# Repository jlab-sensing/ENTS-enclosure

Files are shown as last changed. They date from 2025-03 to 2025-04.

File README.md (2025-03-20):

# ENTS Node Enclosure

If you are looking to get started right away here is the instruction manual! [Instruction Manual](https://docs.google.com/document/d/11tFU89lwRSyXelN36C8FMLKuBJrCtldJ0RzkJU0yMCk/edit?usp=sharing)

### Project Summary

Before beginning the MAE 156 project, researchers using the ENTS generally used an IP68 rated Polycase enclosure to house the node during outdoor deployments. This was an undesirable solution because it was not cost effective at about $49 USD to house a single node and because it required researchers to modify the enclosure to suit their needs regarding cable connections. This was what led the project’s sponsor, Steve Taylor, to form the ENTS team in order to produce a new enclosure with the goal of it also being open-source. There is a need for an enclosure for the ENTS node that follows the following functional requirements: 
   - Low cost (< $40)
   - Accessible to environmental researchers across the country
   - Waterproof
   - Is non-toxic to the environment in which it is deployed in 
   - Does not interfere with data transmission
   - Can allow for variable number of cable connections
   
The goal of the enclosure for the ENTS node is to improve the node's performance for researchers during deployments. Having an enclosure made specifically for their purposes would mean that they would not have to spend resources on tailoring it to their preferences and environments. Having a secure enclosure also prevents leakage, ensuring that the node does not get damaged during deployment. To address these requirements, this project developed two designs: a 3D-printed enclosure using PLA material with a watertight sealant coating, and a PVC enclosure using off-the-shelf components. Both design solutions meet all functional requirements and have their own unique pros and cons. Researchers creating these enclosures pick which design to use based on their specific deployment needs and the tools available to their disposal. 

Here are our two unique enclosure designs (CAD Files are provided as STL & Fusion Files in the repository): 

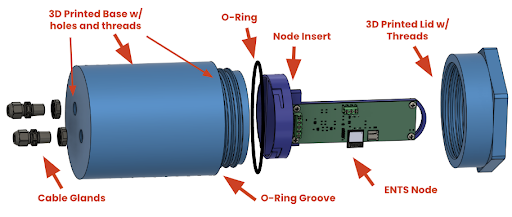
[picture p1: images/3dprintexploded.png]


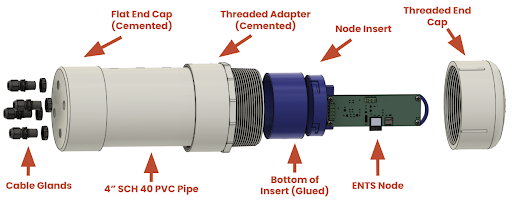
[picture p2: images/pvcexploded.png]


After testing in the Kendall Frost Marsh Reserve, both enclosures demonstrated excellent waterproofing capabilities, lasting a week submerged without water ingress or significant humidity increase. See "Project Links" section below for a detailed enclosure instruction manual, project report and website.  

### Project Links

 - [Website](https://sites.google.com/eng.ucsd.edu/mae156b-2025winter-team11?usp=sharing)
 - [Poster](https://github.com/jlab-sensing/ENTS-enclosure/blob/main/Poster.pdf)
 - [Instruction Manual](https://docs.google.com/document/d/11tFU89lwRSyXelN36C8FMLKuBJrCtldJ0RzkJU0yMCk/edit?usp=sharing)
 - [Final Report](https://docs.google.com/document/d/1t85P1Qo7sQb9_lwukAtd2migy1PWyaXrtm8ifbLmNxY/edit?usp=sharing)

### Editable Fusion 360 CAD Files
 
 - [3D Printed Enclosure](https://a360.co/43Cl2w4)
 - [Twist Lock Insert (PVC)](https://a360.co/41X5OjU)
 - [Twist Lock Insert (3D Print)](https://a360.co/4iIh4pX)

We would like to thank Steve Taylor as well as Nathan Delson and Jerry Tustaniwskyj from the UCSD MAE department for guiding us throughout the project.

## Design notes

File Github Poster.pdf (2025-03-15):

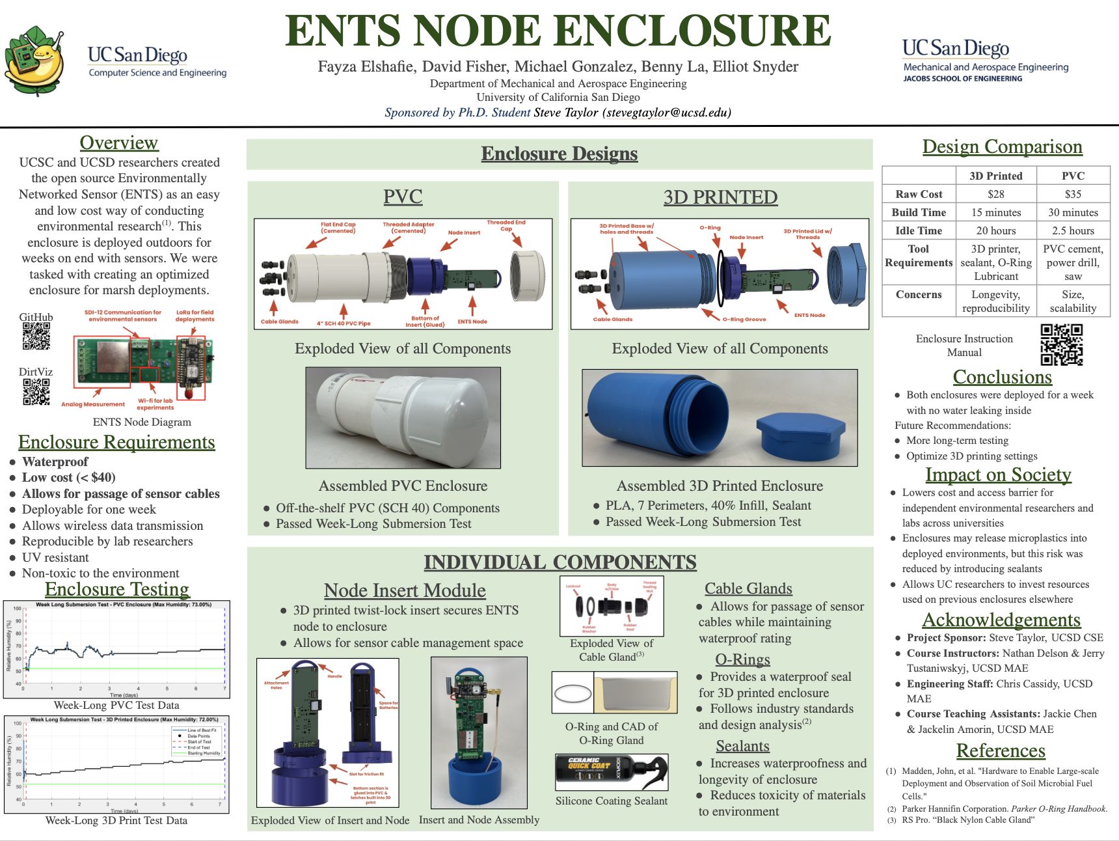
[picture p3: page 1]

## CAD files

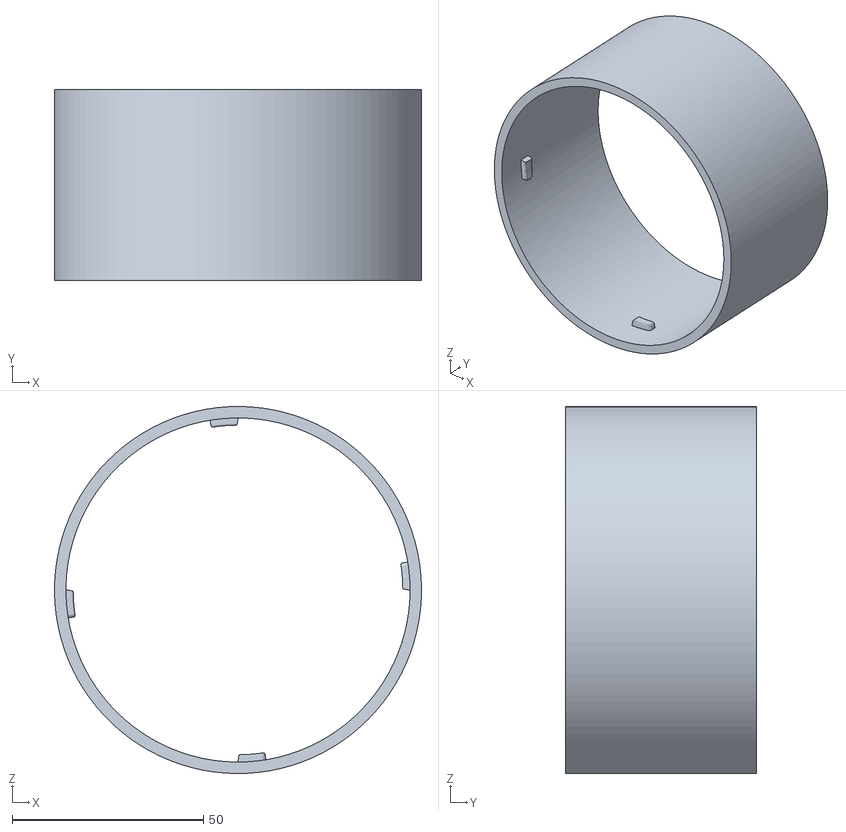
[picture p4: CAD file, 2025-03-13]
design stl files/Twist Lock Insert (PVC) Outer Ring.stl
96.0 x 50.0 x 96.0

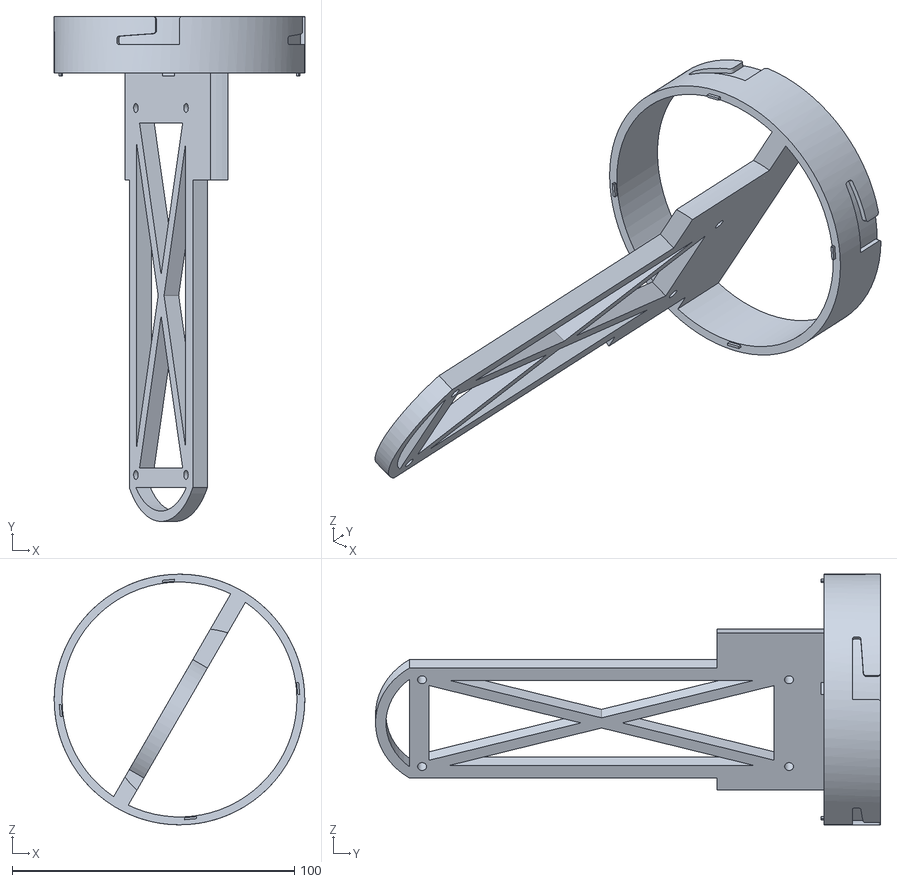
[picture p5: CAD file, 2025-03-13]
design stl files/Twist Lock Insert (PVC) Inner Ring.stl
88.8 x 178.9 x 88.8

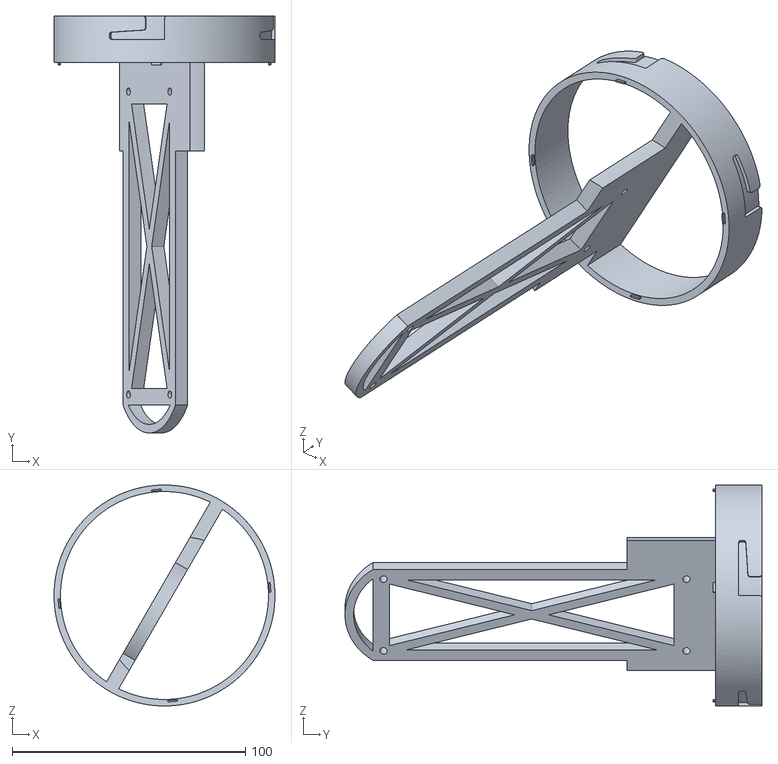
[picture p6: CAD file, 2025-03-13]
design stl files/Twist Lock Insert (3D Print) Inner Ring.stl
94.8 x 178.9 x 94.8

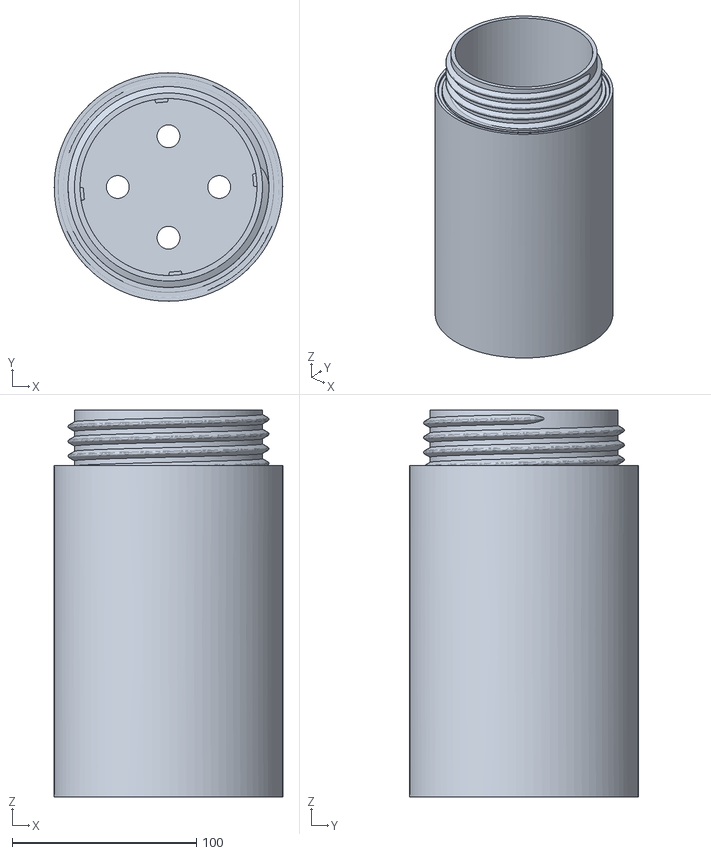
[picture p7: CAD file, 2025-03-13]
design stl files/3D Printed Enclosure Base.stl
124.0 x 124.0 x 210.0

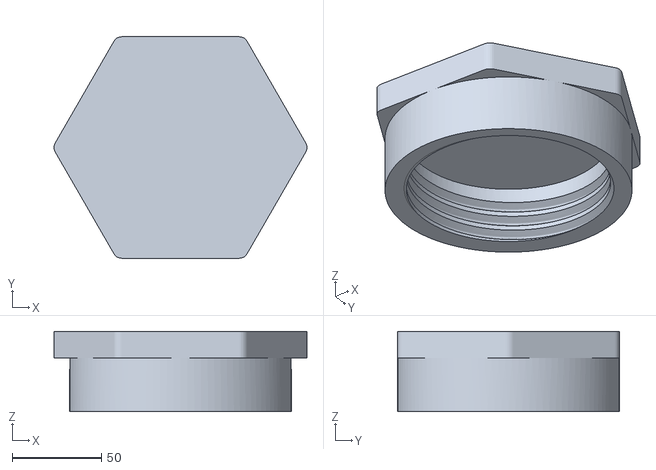
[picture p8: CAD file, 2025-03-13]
design stl files/3D Printed Enclosure Lid.stl
141.6 x 124.0 x 45.0

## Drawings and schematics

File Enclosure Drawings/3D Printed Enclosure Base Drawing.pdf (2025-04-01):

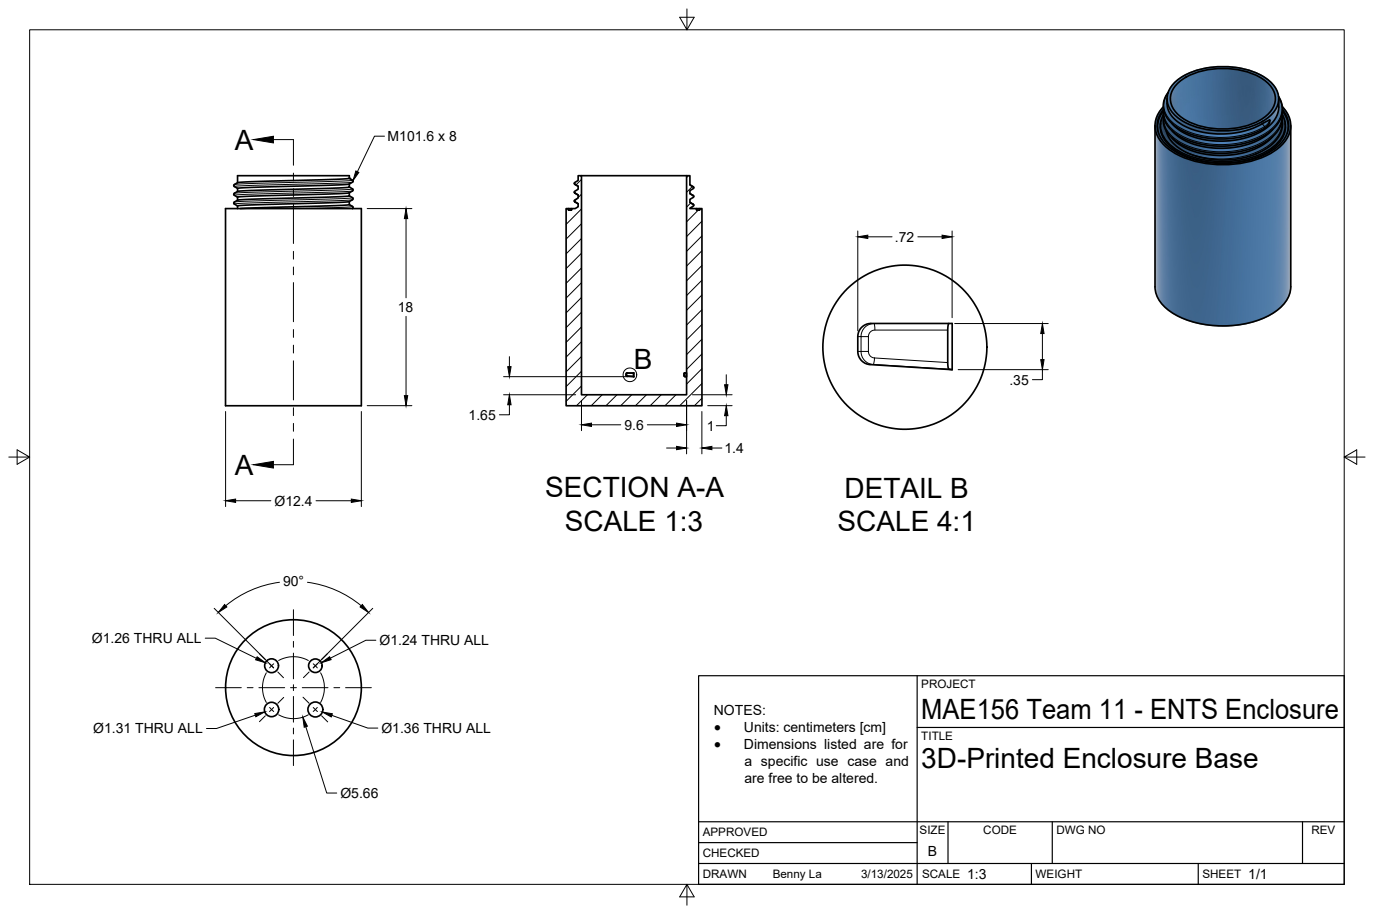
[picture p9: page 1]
SIZE; CODE; DWG NO; REV; Benny La; SECTION A-A SCALE 1:3; DETAIL B SCALE 4:1; Ø1.26 THRU ALL; Ø1.24 THRU ALL; Ø1.31 THRU ALL; Ø1.36 THRU ALL

PROJECT
MAE156 Team 11 - ENTS Enclosure
3D-Printed Enclosure Base

NOTES:
· Units: centimeters [cm]
· Dimensions listed are for
a specific use case and
are free to be altered.

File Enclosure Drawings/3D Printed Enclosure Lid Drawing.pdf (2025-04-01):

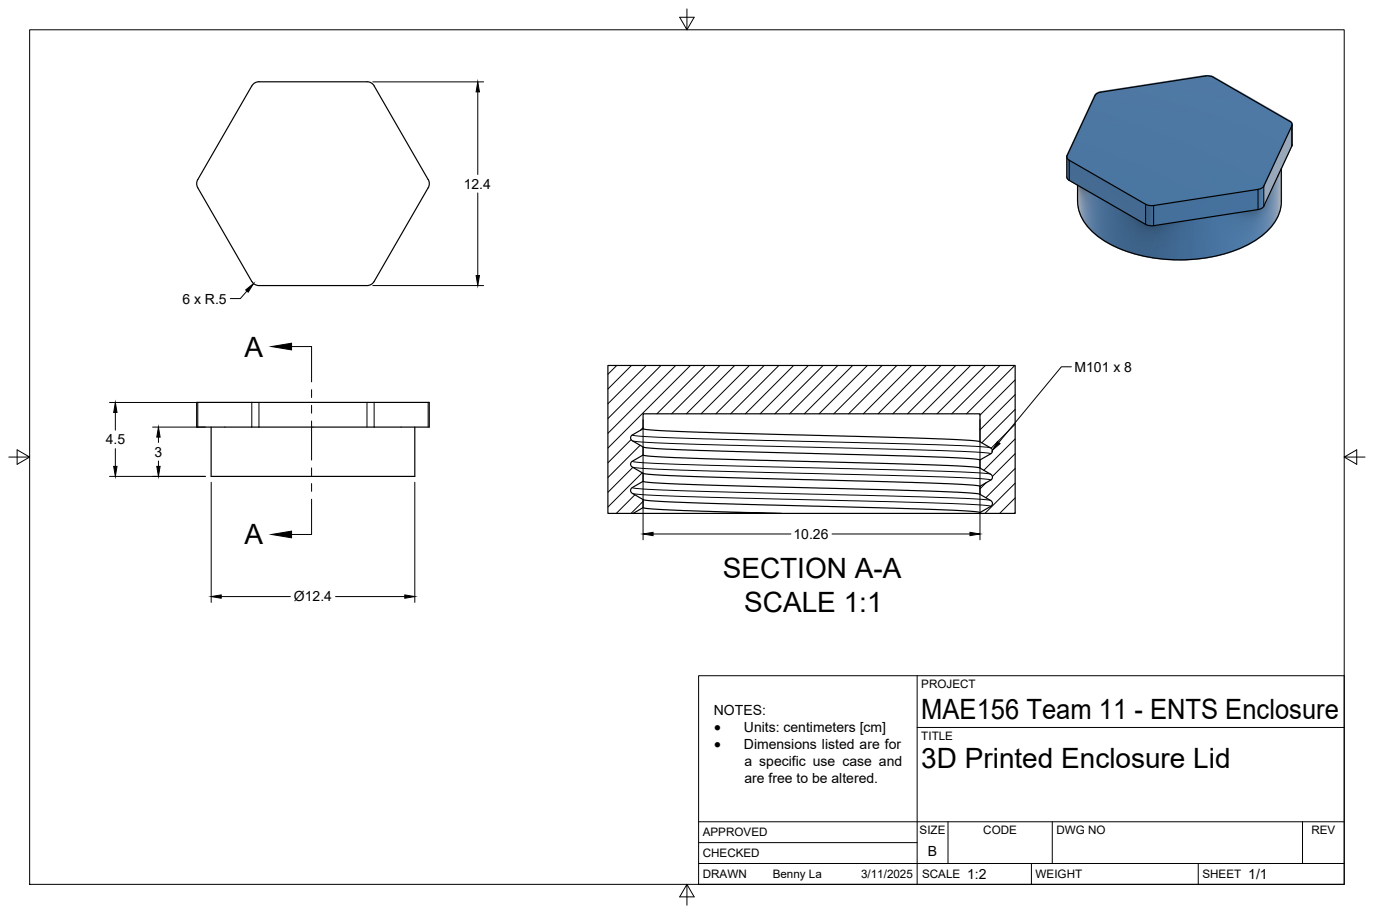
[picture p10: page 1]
SIZE; CODE; DWG NO; REV; Benny La; SECTION A-A SCALE 1:1

PROJECT
MAE156 Team 11 - ENTS Enclosure
3D Printed Enclosure Lid

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

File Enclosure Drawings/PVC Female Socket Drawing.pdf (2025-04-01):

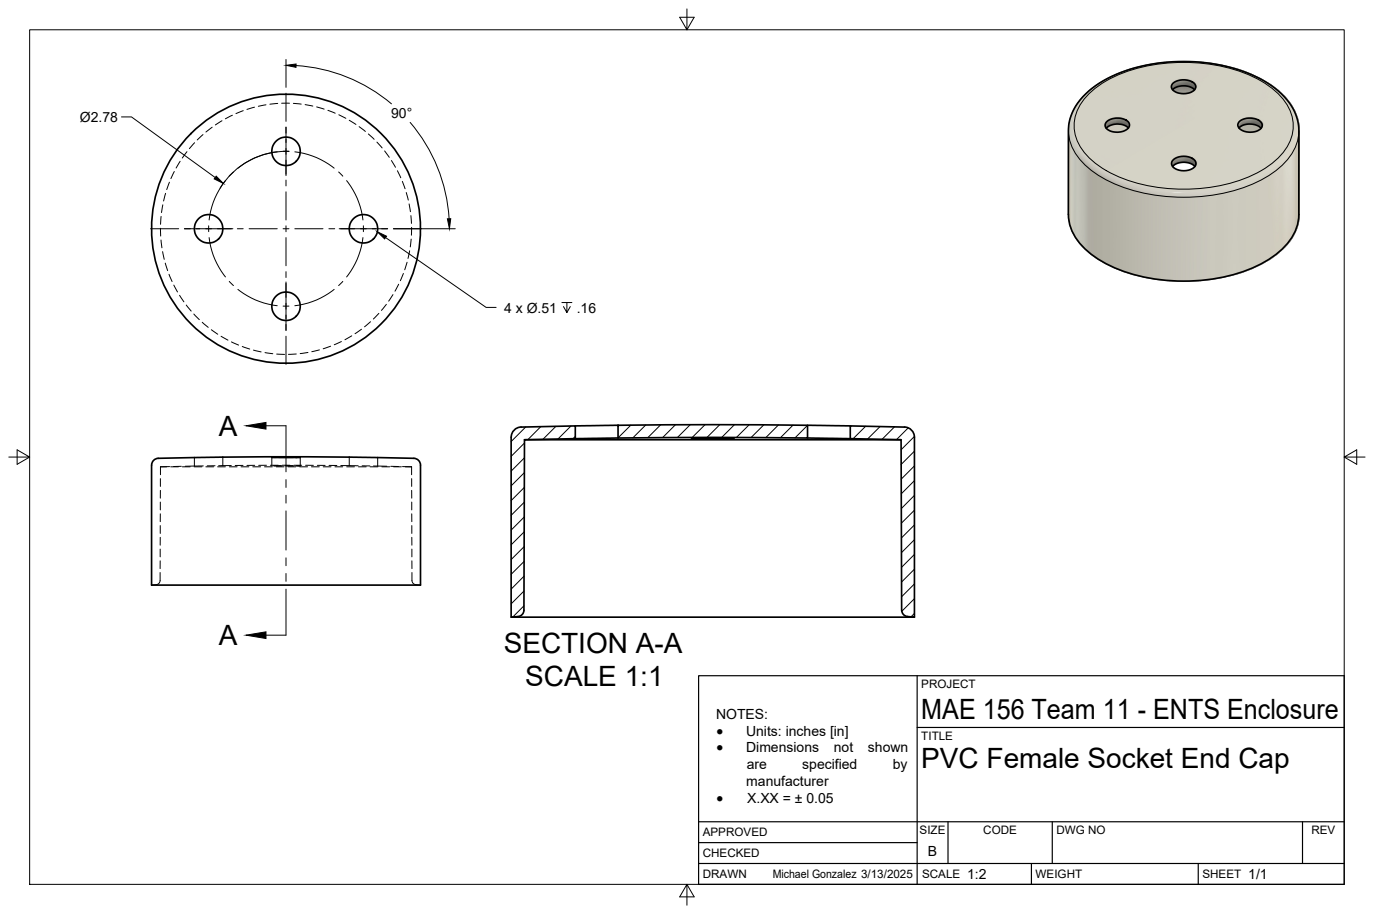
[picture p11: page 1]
SIZE; CODE; DWG NO; REV; Michael Gonzalez 3/13/2025; SECTION A-A SCALE 1:1

PROJECT
MAE 156 Team 11 - ENTS Enclosure
PVC Female Socket End Cap

NOTES:
· Units: inches [in]
· Dimensions not shown
manufacturer

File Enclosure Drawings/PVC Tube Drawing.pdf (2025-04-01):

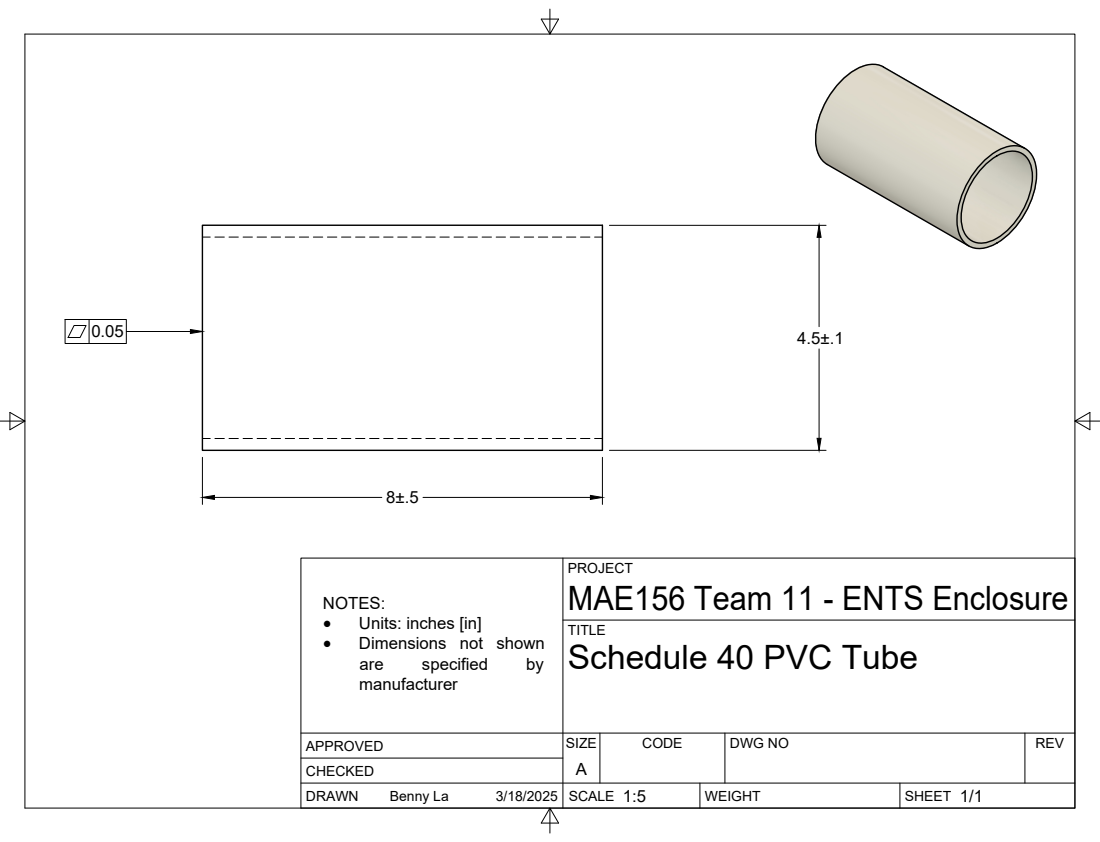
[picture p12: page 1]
SIZE; CODE; DWG NO; REV; Benny La

PROJECT
MAE156 Team 11 - ENTS Enclosure
Schedule 40 PVC Tube

NOTES:
· Units: inches [in]
· Dimensions not shown
manufacturer

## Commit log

2025-02-08 Add files via upload
    Initial proposed 3D-printed enclosure for ENTS Node (Hex Design V4) as of 02/08/2025
    [ENTS_Hex_Enclosure_V4_Base.stl, ENTS_Hex_Enclosure_V4_Lid.stl]
2025-03-13 rework directory structure
    [3D Printed Enclosure.f3d, ENTS_Hex_Enclosure_V4_Base.stl, ENTS_Hex_Enclosure_V4_Lid.stl]
2025-03-13 add design stl files folder
    [3D Printed Enclosure Base.stl, 3D Printed Enclosure Lid.stl, Twist Lock Insert (3D Print) Inner Ring.stl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]
2025-03-15 Rename ENTS Node Enclosure Instruction Manual.pdf to Instruction Manual.pdf
